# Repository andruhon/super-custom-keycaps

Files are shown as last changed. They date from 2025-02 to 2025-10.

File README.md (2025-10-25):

# Super Custom Keycaps

**You need 0.2 mm nozzle to print these keycaps.**

Customizable keycaps with side prints for QMK Tri Layouts opmimized for 3D printing

These keykaps were initially a part of my layout for [TypeS Tri Layout](https://github.com/andruhon/type-s-tri-layout), but it seems like they deserve a separate repo.

Keycaps printed on P1S with AMS, 0.2mm nozzle
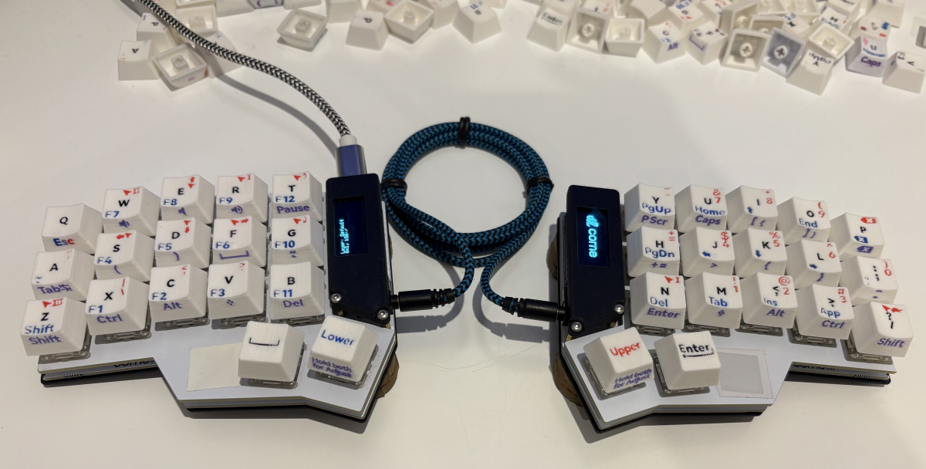
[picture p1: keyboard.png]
Keyboard with full set of keycaps


## Font

Basic font used to create SVG files is Harmony OS Sans Bold.

## Generating keycaps

Generating keycaps requires OpenSCAD of recent version. I'm using 2025.03.25.ai24452,
but it may work with older versions. Try downloading app image of 2025.03.25.ai24452 if you have any compatibility problems.

The best starting point is to open [keycaps-default-all.scad](keycaps-default-all.scad)

A number of other configurations is available:

| File | Description |
| --- | --- |
|[keycaps-default-all.scad](keycaps-default-all.scad) | Standard keycaps in one print |
|[keycaps-default-all-mac.scad](keycaps-default-all-mac.scad) | Mac keycaps in one print |
|[keycaps-default-left.scad](keycaps-default-left.scad) | Standard keycaps left side |
|[keycaps-default-right.scad](keycaps-default-right.scad) | Standard keycaps right side |
|[keycaps-default-mix-hack.scad](keycaps-default-mix-hack.scad) | Allows to print five colours without swapping a roll. See [Mixed colour hack](#mixed-colour-hack)|
|[keycaps-default-one-material.scad](keycaps-default-one-material.scad) | For users without AMS, prints keycaps with grooves instead of filament, can be painted with acryllic paint, nail polish, permanent markers, or left as they are. Prints 4h faster than default all. |
|[keycaps-default-side-unfilled.scad](keycaps-default-side-unfilled.scad) | Leaving side letter unfilled saving 3.5h from default all and reducing poop significantly. |
|[keycaps-default-verbose.scad](keycaps-default-verbose.scad) | Better for beginners or for accidental users. Adjust explicitly tells "hold both", backspace and esc printed three times for each layout |

## Svg preparation process

In Inkscape

- (T) and type letter
- (CTRL+SHIFT+C) to convert letter to path
- (CTRL+SHIFT+D) and then select resize to content
- (CTRL+SHIFT+E) type file name matching short QMK code, select "Plain SVG" and click Export.

Once new svg is added to `/svg` directory the `node measure-svg.js` has to be executed.

## Printing

When loading 3mf or stl file the slicer is likely to ask you
`The object from file keycaps.3mf is too small, and may be in meters or inches. Do you want to scale to millimeters?`
Answer **No**. The file is already in milimeters. It's just keycaps relatevly small.

The next question is
`This file contains several objects positioned at multiple heights. Instead of considering them as multiple objects, should the file be loaded as a single object having multiple parts?`
Answer **Yes**. We don't want letters to end up separately from keycaps.

Go to `Objects`. The object should have five parts. Allocate colours to parts to your liking.

- You need 0.2 mm nozzle to print these keycaps.
- Layer height 0.1 mm
- Exported 3mf file will have 4 subparts. Allocate desired colours to them.
- No supports. Buttons are small enough bridging should work well.
- No AUX fan. Stems will peel if it's on, generally buttons closer to the fan look worse.
- Top layer and infill - Aligned rectilinear.
- Infill direction 90
- Top shell layers 16 to avoid sparse infill (sparce infill won't save anything on such small prints)
- Seams position: Back

## Mixed colour hack
I accidentaly found that one 0.1mm lyer of blue on top of one layer of red
looks almost like black. Which allows a hacky way to produce 5 colour print out of one AMS without swapping roll.

The [keycaps-default-mix-hack.scad](keycaps-default-mix-hack.scad) aplies this hack for center letter,
printing one layer of blue on top of red, making it look nearly as black.

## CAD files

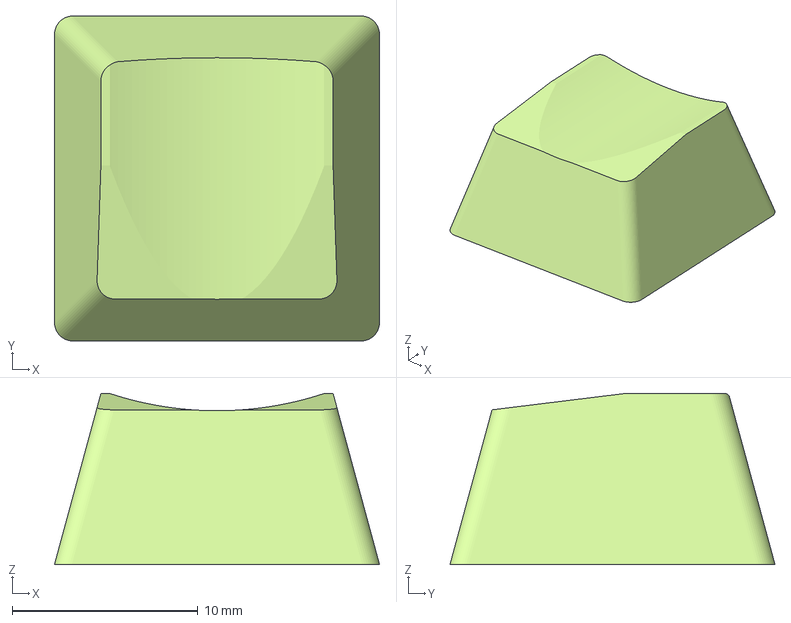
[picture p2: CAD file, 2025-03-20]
bodies/cylindric-concave-thumb.3mf
17.5 x 17.5 x 9.21 mm

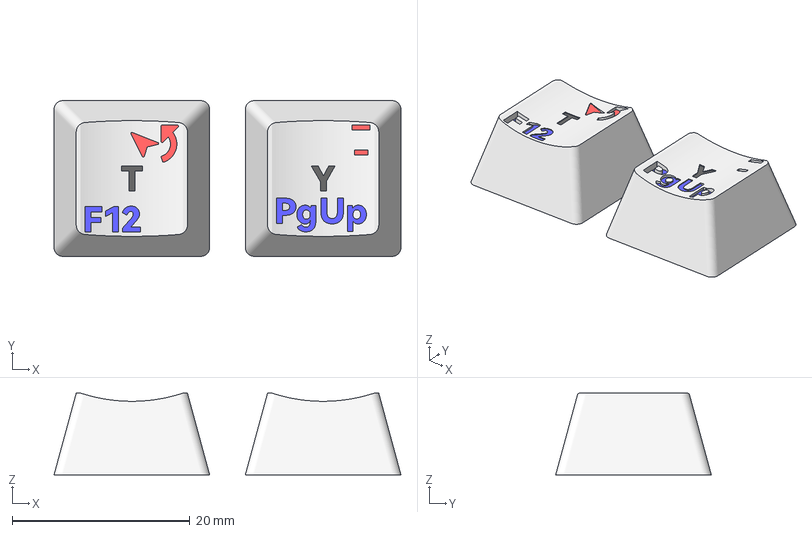
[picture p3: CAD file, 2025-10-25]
keycaps-default-mac-ty.3mf
39.0 x 17.5 x 9.21 mm

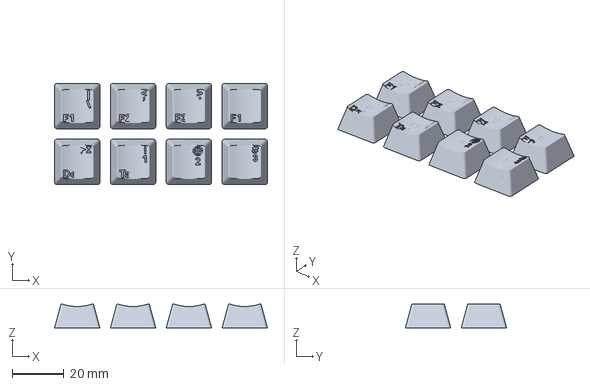
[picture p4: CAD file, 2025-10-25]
keycaps-default-mac-action-only.3mf
82.0 x 39.0 x 9.21 mm

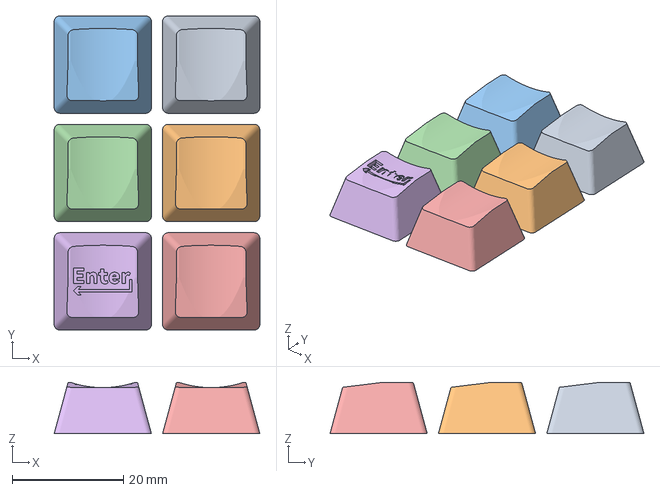
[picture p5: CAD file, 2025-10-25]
enter-and-blanks.3mf
37.0 x 56.5 x 9.21 mm
cylindric-concave-thumb x 5
keycaps-sampler_B

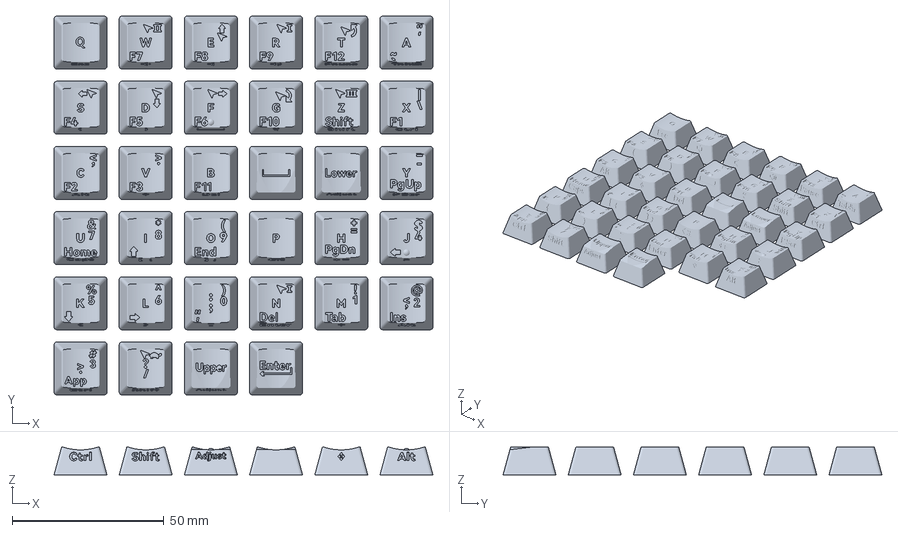
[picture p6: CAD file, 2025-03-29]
keycaps-default-one-material.3mf
125.0 x 125.0 x 9.21 mm

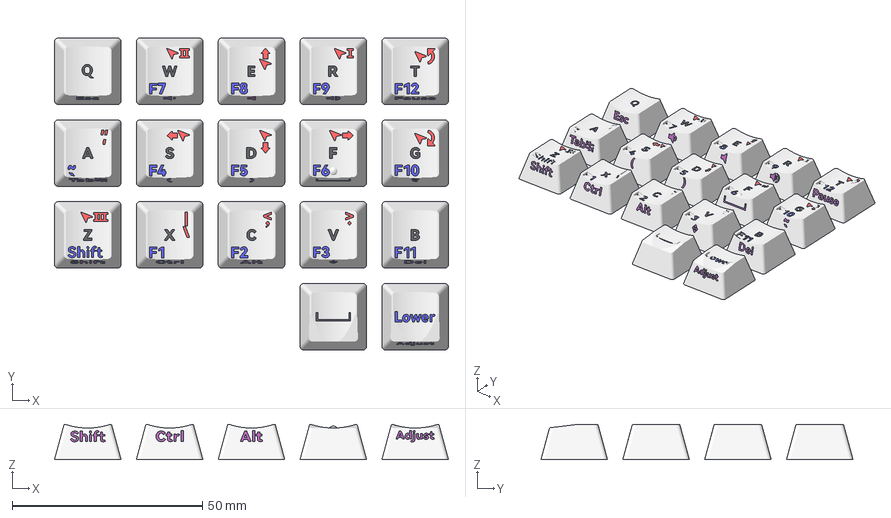
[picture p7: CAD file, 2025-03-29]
keycaps-default-left.3mf
103.5 x 82.0 x 9.21 mm

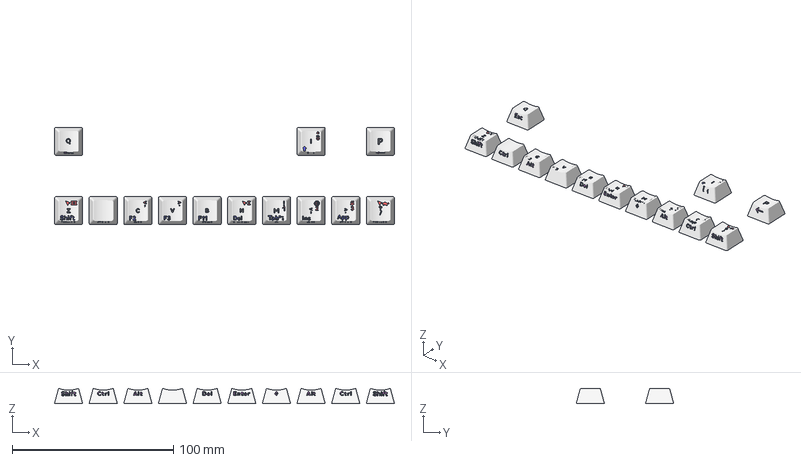
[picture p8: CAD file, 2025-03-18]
keycaps.3mf
211.0 x 60.5 x 9.21 mm

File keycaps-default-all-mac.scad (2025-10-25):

include <keycaps-inner.scad>;

/**
 * ----------------------------------------------
 * Config
 * Default setup with all keycaps using 5 colours.
 * Data with keys follows below.
 * ----------------------------------------------
 */
KEYCAP_WIDTH = 17.5;
KEYCAP_HEIGHT = 9.2;
KEYCAP_SURFACE_LOWEST_POINT = 8.28; // Lowest point on the surface
KEYCAP_SURFACE_WIDTH = 10.5;
KEYCAP_SURFACE_LENGTH = 12;
KEYCAP_CONVEXITY = 7; // To address preview issues
KEYCAP_COLOUR = "LightGrey"; // This color and others below are for preview TO_RENDER

/**
 * SPACING between keycaps
 */
SPACING = 4;
LAYER_HEIGHT = 0.1; // With 0.2 nozzle the layer height is usually 0.1
LAYER_LINE_WIDTH = 0.22;
PRINT_DEPTH = LAYER_HEIGHT * 2; // Best when it is double layer height
SURFACE_DIFF_DEPTH = KEYCAP_HEIGHT - KEYCAP_SURFACE_LOWEST_POINT + PRINT_DEPTH;

SURFACE_PRINT_ANGLE = 0; // In the case surface is at angle

/**
 * Surface Center Print (for Base layer)
 */
SURFACE_CENTER_PRINT_COLOUR = "black";
SURFACE_CENTER_PRINT_RELATIVE_Y = 0;

/**
 * Leaving one layer above the colour
 * The calculation should be KEYCAP_SURFACE_LOWEST_POINT - PRINT_DEPTH - LAYER_HEIGHT,
 * but we want it to be dividable by layer height
 */
SURFACE_CENTER_PRINT_POSITION_Z = KEYCAP_SURFACE_LOWEST_POINT - PRINT_DEPTH - LAYER_HEIGHT;

/**
 * Surface Upper Right Print (for Upper / Raise layer)
 */
 SURFACE_RIGHT_PRINT_COLOUR = "red";
 SURFACE_RIGHT_PRINT_POSITION_Z = SURFACE_CENTER_PRINT_POSITION_Z;
 
/**
 * Surface Lower Left Print (for Lower layer)
 */
 SURFACE_LEFT_PRINT_COLOUR = "blue";
 SURFACE_LEFT_PRINT_POSITION_Z = SURFACE_CENTER_PRINT_POSITION_Z;

/**
 * Side print (for Adjust Layer)
 */
SIDE_FILL = true; // Should the side (longest part of the print be filled?)
SIDE_PRINT_ANGLE = 74.798;
SIDE_PRINT_POSITION_Z = 6;
SIDE_PRINT_RELATIVE_Y = -6.67;
SIDE_PRINT_COLOUR = "purple";

HOME_ROW_PIMPLE_DIAMETER = 3;
HOME_ROW_PIMPLE_RELATIVE_Y = -(KEYCAP_WIDTH/2 - 4);
HOME_ROW_PIMPLE_RELATIVE_Z = KEYCAP_SURFACE_LOWEST_POINT - 5.6;

/**
 * Place one layer of center into right and one layer of center into left,
 * because 0.1mm of filament is nearly tranclucent it makes colours mix,
 * the mixture of red and blue looks nearly black.
 * This allows to have fifth colour with single AMS unit.
 * I think this is only going to be helpful if body is white.
 */
MIXED_COLOUR_CENTER = false;

/**
 *Default keycap body to be rendered if alternative not provided
 */
DEFAULT_BODY = "bodies/cylindric-concave.3mf";

/**
 * To render selected part
 * Options are: all, body, print, center, left, right, side
 */
TO_RENDER = "all";

/**
 * Either place keys in a precise layout you configured them,
 * or just in a number of rows one by one
 */
AUTO_LAYOUT = false;
AUTO_LAYOUT_KEYS_PER_ROW = 5;

/**
 * Number of rows in one side
 */
SIDE_BUTTON_ROWS_COUNT = 5;
VERBOSE_LABELS = false;

KC_Q = keycap(0, 0, center_svg = "KC_Q",    side_svg = "KC_ESC");
KC_Q_VERBOSE = keycap(0, 0, center_svg = "KC_Q", left_svg = "KC_ESC", right_svg = "KC_ESC", side_svg = "KC_ESC");
LOWR = keycap(3, 4, body="bodies/cylindric-concave-thumb.3mf", left_svg = "TL_LOWR", side_svg = "ADJUST", left_relative_y=0);
LOWR_VERBOSE = keycap(3, 4, body="bodies/cylindric-concave-thumb.3mf", left_svg = "TL_LOWR", side_svg = "ADJUST_v", side_position_z=3.3, side_relative_y=-7.4, left_relative_y=0);

KC_P = keycap(0, 9, center_svg = "KC_P",    side_svg = "KC_BSPC_s");
KC_P_VERBOSE = keycap(0, 9, center_svg = "KC_P", left_svg = "KC_BSPC_s", right_svg = "KC_BSPC_s", side_svg = "KC_BSPC_s");

UPPR = keycap(3, 5, body="bodies/cylindric-concave-thumb.3mf", right_svg  = "TL_UPPR", side_svg = "ADJUST", right_relative_y=0);
UPPR_VERBOSE = keycap(3, 5, body="bodies/cylindric-concave-thumb.3mf", right_svg  = "TL_UPPR", side_svg = "ADJUST_v", side_position_z=3.3, side_relative_y=-7.4, right_relative_y=0);


// Data to to render keycaps
keycaps = [
    // Left
    VERBOSE_LABELS ? KC_Q_VERBOSE : KC_Q,
    keycap(0, 1, center_svg = "KC_W",    left_svg = "KC_F7",    right_svg = "MS_BTN2",  side_svg = "KC_VOLD"),
    keycap(0, 2, center_svg = "KC_E",    left_svg = "KC_F8",    right_svg = "MS_UP",    side_svg = "KC_MUTE"),
    keycap(0, 3, center_svg = "KC_R",    left_svg = "KC_F9",    right_svg = "MS_BTN1",  side_svg = "KC_VOLU"),
    keycap(0, 4, center_svg = "KC_T",    left_svg = "KC_F12",   right_svg = "MS_WHLU"                       ),
    
    keycap(1, 0, center_svg = "KC_A",    left_svg = "KC_GRV",   right_svg = "KC_QUOT",  side_svg = "KC_TAB_i"),
    keycap(1, 1, center_svg = "KC_S",    left_svg = "KC_F4",    right_svg = "MS_LEFT",  side_svg = "KC_LPRN"),
    keycap(1, 2, center_svg = "KC_D",    left_svg = "KC_F5",    right_svg = "MS_DOWN",  side_svg = "KC_RPRN"),
    keycap(1, 3, center_svg = "KC_F",    left_svg = "KC_F6",    right_svg = "MS_RGHT",  side_svg = "KC_SPC", home_row = true),
    keycap(1, 4, center_svg = "KC_G",    left_svg = "KC_F10",   right_svg = "MS_WHLD",  side_svg = "KC_GRV"),

    keycap(2, 0, center_svg = "KC_Z",    left_svg = "KC_LSFT",  right_svg = "MS_BTN3",  side_svg = "KC_LSFT"),
    keycap(2, 1, center_svg = "KC_X",    left_svg = "KC_F1",    right_svg = "KC_BSLS",  side_svg = "KC_MCTL"),
    keycap(2, 2, center_svg = "KC_C",    left_svg = "KC_F2",    right_svg = "KC_COMM",  side_svg = "KC_MOPT"),
    keycap(2, 3, center_svg = "KC_V",    left_svg = "KC_F3",    right_svg = "KC_DOT",   side_svg = "KC_MCMD"),
    keycap(2, 4, center_svg = "KC_B",    left_svg = "KC_F11",                           side_svg = "KC_MFN"),

    keycap(3, 3, body="bodies/cylindric-concave-thumb.3mf", center_svg = "KC_SPC"),
    VERBOSE_LABELS ? LOWR_VERBOSE : LOWR,

    // Rigth
    keycap(0, 5, center_svg = "KC_Y",    left_svg = "KC_PGUP",  right_svg = "KC_MINS"                       ),
    keycap(0, 6, center_svg = "KC_U",    left_svg = "KC_HOME",  right_svg = "KC_7",     side_svg = "KC_CAPS"),
    keycap(0, 7, center_svg = "KC_I",    left_svg = "KC_UP",    right_svg = "KC_8",     side_svg = "KC_LBRC"),
    keycap(0, 8, center_svg = "KC_O",    left_svg = "KC_END",   right_svg = "KC_9",     side_svg = "KC_RBRC"),
    VERBOSE_LABELS ? KC_P_VERBOSE : KC_P,

    keycap(1, 5, center_svg = "KC_H",    left_svg = "KC_PGDN",  right_svg = "KC_EQL",   side_svg = "KC_EQL_s"),
    keycap(1, 6, center_svg = "KC_J",    left_svg = "KC_LEFT",  right_svg = "KC_4",     side_svg = "KC_RABK", home_row = true),
    keycap(1, 7, center_svg = "KC_K",    left_svg = "KC_DOWN",  right_svg = "KC_5",     side_svg = "KC_LCBR"),
    keycap(1, 8, center_svg = "KC_L",    left_svg = "KC_RGHT",  right_svg = "KC_6",     side_svg = "KC_RCBR"),
    keycap(1, 9, center_svg = "KC_SCLN", left_svg = "KC_QUOT",  right_svg = "KC_0",     side_svg = "KC_MINS"),
    
    keycap(2, 5, center_svg = "KC_N",    left_svg = "KC_DEL",   right_svg = "MS_BTN1",  side_svg = "KC_MFN"),
    keycap(2, 6, center_svg = "KC_M",    left_svg = "KC_TAB",   right_svg = "KC_1",     side_svg = "KC_MCMD"),
    keycap(2, 7, center_svg = "KC_COMM",                        right_svg = "KC_2",     side_svg = "KC_MOPT"),
    keycap(2, 8, center_svg = "KC_DOT",                         right_svg = "KC_3",     side_svg = "KC_MCTL"),
    keycap(2, 9, center_svg = "KC_SLSH",                        right_svg = "MS_ACL0",  side_svg = "KC_LSFT"),

    VERBOSE_LABELS ? UPPR_VERBOSE : UPPR,
    keycap(3, 6, body="bodies/cylindric-concave-thumb.3mf", center_svg = "KC_ENT_i")
    
];

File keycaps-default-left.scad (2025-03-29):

include <keycaps-default-all.scad>;

SIDE = "left";

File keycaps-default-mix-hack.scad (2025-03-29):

include <keycaps-default-all.scad>;

MIXED_COLOUR_CENTER = true;
AUTO_LAYOUT = true;
AUTO_LAYOUT_KEYS_PER_ROW = 6;

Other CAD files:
bodies/cylindric-concave.3mf
keycaps-sampler.3mf
keycaps-default-right.3mf
keycaps-default-all.scad
bodies/cylindric-concave.scad
bodies/polyhedron3.scad
keycaps-default-one-material.scad
keycaps-default-right.scad
keycaps-default-side-unfilled.scad
keycaps-default-verbose.scad
keycaps-inner.scad
svg_dimensions.scad

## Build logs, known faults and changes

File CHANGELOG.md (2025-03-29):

# Changelog

I'm trying to design keycaps which are good when printed on
3D printer with AMS or similar material changing system.

## 27 Mar 2025

I was swapping one roll of filament to produce 5-colour print with one single AMS unit, which only has 4 colours.
I screwed up the swap in the last print, but accidentaly found that one 0.1mm lyer of blue on top of one layer of red
looks almost like black. Which allows a hacky way to produce 5 colour print out of one AMS without swapping roll.
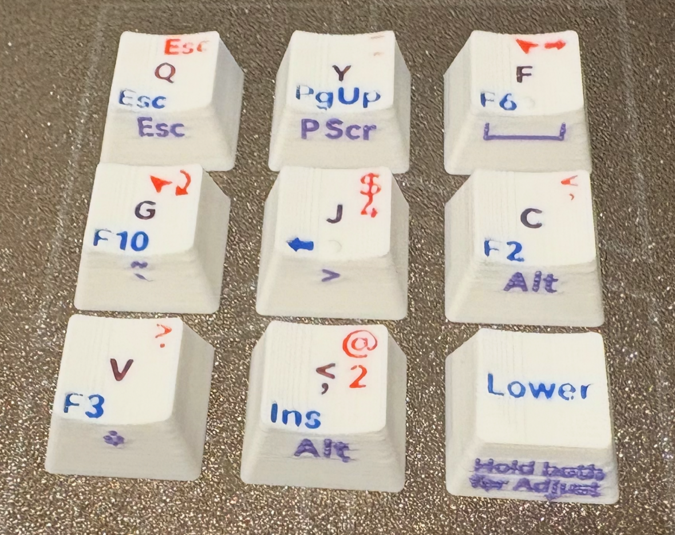
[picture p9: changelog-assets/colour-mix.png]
Hacky Mixed Colour


Introduced MIXED_COLOUR_CENTER parameter.

## 26 Mar 2025

All SVGs are finally ready! Sent remaining keys to print.

## 20 Mar 2025

Trying to set slower speed for top surface layer to improve quality.

## 17 Mar 2025

It is slowly getting shape!

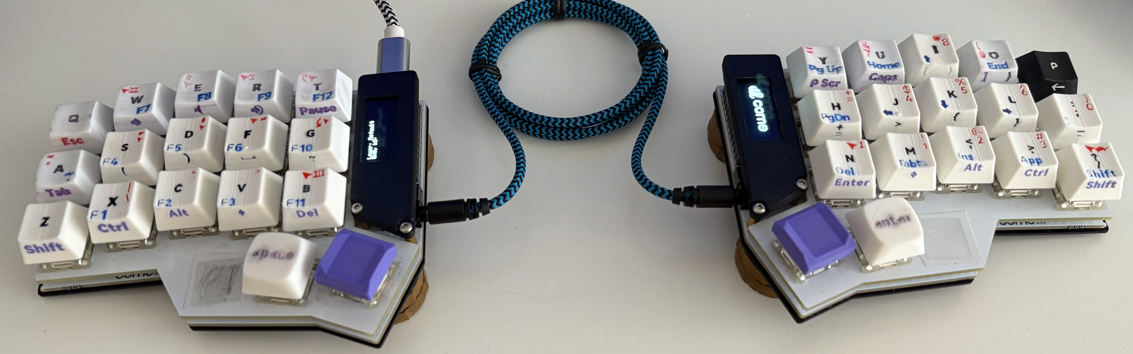
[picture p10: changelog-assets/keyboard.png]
Keyboard with almost full set of keycaps


Achieved five colours with adding Pause onto one of white layers between side prints and top rints,
to replace Purple filament with Blue filament. As long as we never have all 5 colours in one layer it works great.

It is early autumn in New Zealand and humidity outside is already close to 100%, nearing 80% inside.
I need to dry my filament better, observed some stringing with my last print.

## 16 Mar 2025

After failure with JSCAD I decided to tidy up my OpenSCAD scripts. Upgraded to OpenSCAD-2025.03.12.

Even though JSCAD has less problems extruding SVG this does not mean it all rainbows and unicorns there.
One of the biggest reasons I wanted to switch to JSCAD was that it is not possible in OpenSCAD to measure
objects, for example it is not possible to get dimensions of newly imported SVGs, as well as it is not possible
to align them relatively. The only alignment available is "center" at import time.

Working around this limitation of OpenSCAD was somewhat easier than figuring out how extrusions work in JSCAD:
I simply created extra JS script which scans directory with SVG files, reads their box dimensions and then
writes them into scad file which can later be imported into scad script.

The alignment algorithm seems to be working well with SVGs of different sizes:  
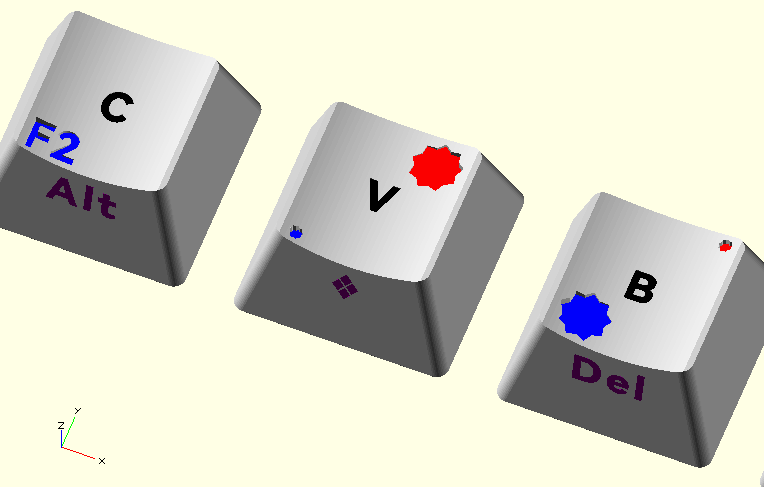
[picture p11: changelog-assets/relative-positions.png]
Aligned icons


!!! Idea !!! SVG file names should match QMK codes! Hypothetically I can later work out script to convert keymap.c to data for keycaps.scad

## 15 Mar 2025

OpenSCAD language feels a bit awkward for me, I had hopes to make it easier writing JavaScript with JSCAD (aka OPENJSCAD),
and it all looked good, until I tried to extrude my SVGs. So far JSCAD is really weak with extruding SVGs.
See https://github.com/jscad/OpenJSCAD.org/issues/1253, https://github.com/jscad/OpenJSCAD.org/issues/1087 and https://github.com/jscad/OpenJSCAD.org/issues/1386

## 7 Mar 2025

Looking at my old coloured keycaps I can conclude that permanent marker wears over time, acrylic paint seems to be in a good shape and automotive enamel not showing any detereoration at all.

## 3 Mar 2025

Decided that it's better to have every symbol in a separate file.
This will help me exporting for 3D printing (with separate file for each material).

## 26 Feb 2025

Moved keycaps from https://github.com/andruhon/34KeysLayoutQMK into this separate repo.

## 23 Feb 2025

Printed first keycaps on P1S with AMS with 0.2mm nozzle. They look really nice!
Concluded that keycaps are small enough and don't really need support if infill selected correctly.  
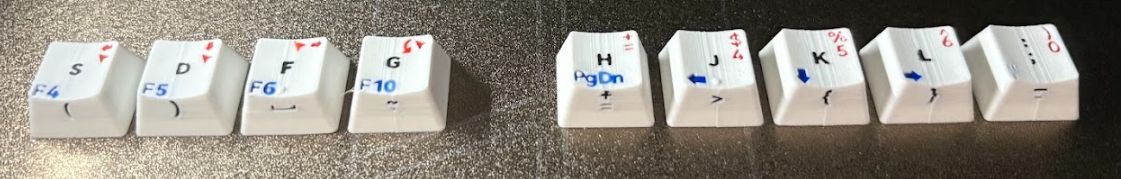
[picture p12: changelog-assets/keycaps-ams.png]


## 27 Nov 2024

A photograph of different prototypes on my keyboard
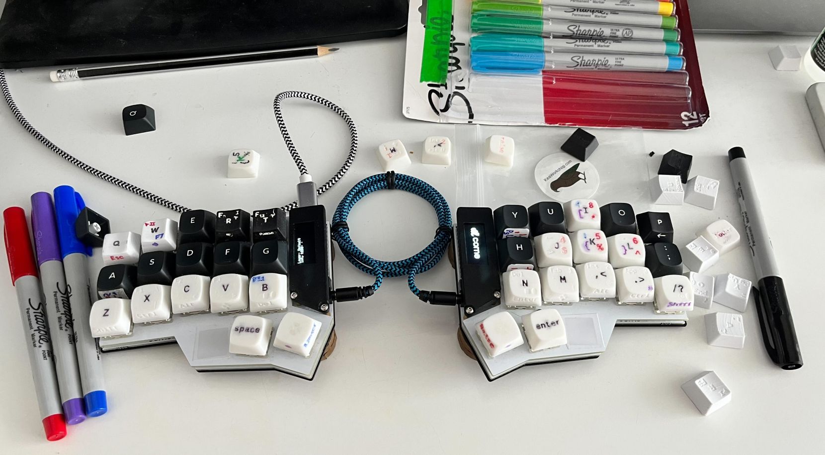
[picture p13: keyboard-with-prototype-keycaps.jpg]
Keyboard


- P,T and R are from newcaps.scad - illed with automotive enamel and sanded.
- zxcvbnmjkli and thumb cluster are from keycap-edit-gui.scad painted with ultra fine point permanent markers. These caps currently have some advantage that they do not need to be sanded - they come smooth enough by themselves, because they are flat.
- Q and W are also from newcaps.scad, but painted with permanent marker. Q first painted and sanded, P first sanded then painted. It is important to notice that layer lines work as capillary and suck all the paint, so it is preferrable to sand the button first.
- Black keys except R,T and P are Keychron caps.

## 24 Nov 2024

It is getting hard to get in to the queue in the library, also they refuse to do any tinkering with settings printing everything on defaults. I decided to print a few keycaps for money in local worksop (it is not cheap).
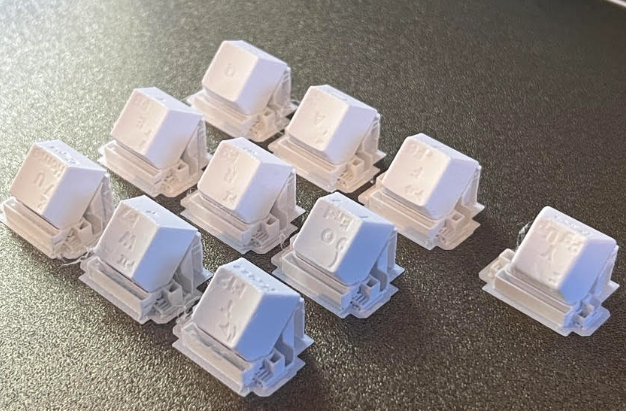
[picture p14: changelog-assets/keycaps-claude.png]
Keycaps from Claude


Tried to colour new keycaps and found that because they were printed at an angle they have notable bleeding of permanent marker paint.
On the picture below L with 6 and arrow right is coloured with acrylic paint (except curly brace, which is a permanent marker);
P is sanded and coloured with automotive enamel;
Q with Esc is panted with permanent marker and has notable bleeding.  
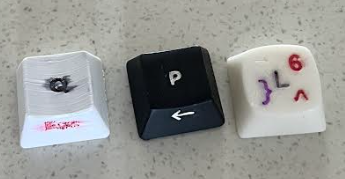
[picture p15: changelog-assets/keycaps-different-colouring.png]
Different colouring of keycaps


Most of bleeding has came off from Q after sanding, but it seems like some of that has penetrated deeper:  
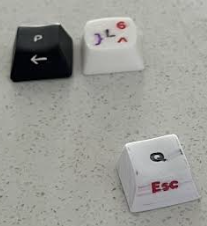
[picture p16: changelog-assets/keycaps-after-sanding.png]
After sanding


Sanded W with mouse 2 before painting, and no bleeding observed:  
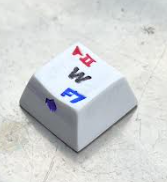
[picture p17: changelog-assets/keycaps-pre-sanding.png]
Pre sanding


## 20 Nov 2024

Started building my own profile with concave and cyllindric stems and extra print on front side. Unfortunately library have ran out of white filament, so I decided to print my new keycaps with concave in black. Black filament turned to be more fragile.
Tried colouring them with nail polish, acrylic paint and car enamel. Only P with backspace pinted with white automotive enamel survived.

## 26 Oct 2024

Had issues with stems on both Riskable and Aileron profiles. They either too loose, or too fragile. Not sure why Aileron keycaps have rectangular stem, so they cannot be placed on side.

## 22 Oct 2024

Ordered to print my keykaps in Makerspace of local library. It took 10 days to get to the tip of the queue and get my first prototypes. I started with flat keycaps from karlh592 (aileron.me).
The flat keycap was K with arrow down on lower, and 5 raise. I also printed a few blank keycaps from https://github.com/riskable/keycap_playground/, it seems like they are really optimized for FDM and feel good to touch.
I initially intended to print colour infill like described in https://aileron.me/app/keycap , but guys from library said that they have not capacity (in terms of quque length) to do multi-colour printing.
Aileron, keycaps also look really nice and I figured out that I can paint letter grooves with permanent markers or nail polish. While they are nice keycaps with concave are a lot better to type on.

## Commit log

2025-02-26 Remove original repo files
    [button-polyhedron.stl, button-polyhedron3.stl, button-presoft.3mf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]
2025-02-27 Keycaps printed with AMS
2025-03-02 start optimizing for 3D printing
    [button-presoft.3mf, h.3mf, newcap.scad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]
2025-03-15 start refactoring keycaps generator
    [button-polyhedron.stl, button-polyhedron3.stl, cylindric-concave.3mf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]
2025-03-16 Add svg parsing script
    [keycaps.scad, svg_dimensions.scad]
2025-03-16 Apply alignment using precomputed SVG box sizes
    [keycaps.scad, svg_dimensions.scad]
2025-03-16 tidy up SVG files
    [keycaps.scad, svg_dimensions.scad]
2025-03-16 add more keys
    [keycaps.3mf, keycaps.scad, svg_dimensions.scad]
2025-03-18 Move keycaps out of tautologic directory
    [cylindric-concave.3mf, cylindric-concave.scad, keycaps.3mf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]
2025-03-18 add changes from layout, update instructions
    [keycaps.3mf, keycaps.scad, svg_dimensions.scad]
2025-03-18 correct typos
    [keycaps.3mf, keycaps.scad, svg_dimensions.scad]
2025-03-19 keycaps WIP
    [keycaps.scad, svg_dimensions.scad]
2025-03-19 update a few laters
    [keycaps.scad, svg_dimensions.scad]
2025-03-19 fis base bug
    [keycaps.scad]
2025-03-20 add profile for thumb-cluster
    [cylindric-concave-thumb.3mf, cylindric-concave.scad, keycaps.scad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]
2025-03-26 add more letters
    [keycaps.scad, svg_dimensions.scad]
2025-03-26 all keys!
    [keycaps.scad, svg_dimensions.scad]
2025-03-26 use verbose adjust as default
    [keycaps.scad, svg_dimensions.scad]
2025-03-27 add home row pimple
    [keycaps.scad, svg_dimensions.scad]
2025-03-27 new adjust dimensions
    [svg_dimensions.scad]
2025-03-28 add option to use mised colour hack
    [keycaps.scad]
2025-03-28 update README.md: add notes for slicer messages
    [keycaps.scad]
2025-03-28 smoother pimples
    [keycaps.scad]
2025-03-28 fix floating region of cuboid
    [keycaps.scad]
2025-03-29 cleanup for release
    [keycaps-default-all.scad, keycaps-default-left.3mf, keycaps-default-left.scad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]
2025-10-25 add mac keys
    [enter-and-blanks.3mf, keycaps-default-all-mac-action-only.3mf, keycaps-default-all-mac.scad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]
2025-10-25 remove pause
    [keycaps-default-all-mac.scad]
2025-10-25 mac t an y
    [keycaps-default-mac-action-only.3mf, keycaps-default-mac-ty.3mf]
